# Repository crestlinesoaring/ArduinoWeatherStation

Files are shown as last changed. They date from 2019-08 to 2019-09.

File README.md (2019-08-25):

# ArduinoWeatherStation
### Open source weather station code and hardware for foot launched flight (FLF)

## Assumptions: 
- You have a bash style shell 
-- Linux: terminal
-- Windows: [GitBash for Windows | https://gitforwindows.org/ ]
- There is a root folder that you use for for development
-- referred to as $DEV_HOME
-- I use ~/Development (or C:\Development)

## Software Requirements

- Development tools Setup
-- [Arduino IDE | https://www.arduino.cc/en/Main/Software]

## Hardware Requirements
-- Arduino Mega
-- Brain board (TODO: needs circuit diagram and parts list etc) 

## Get and Build Software

-- Clone this repo (and submodules)

`
git clone --recursive https://github.com/crestlinesoaring/ArduinoWeatherStation.git
`

## Installation

## Testing (Bench) 

## Forks/Contributions
The goal is to build a robust and readily reproduced weather station for FLF oriented micro-meterology. Forks, contributions, issue reports and constructive feedback are welcome. 
Please contact: [Project Coordinator] for more informtaion on contributing source code.

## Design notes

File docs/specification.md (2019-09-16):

++ Weather Station Specifications

* When the local time is 2 hours before sunrise
*  And battery capacity is at or above 25%
* Then System shall store weather data to external eeprom every 5 minutes

* When the local time is after sunrise
*  And Solar panel production exceeds 50% of capacity
*  Or battery capacity is at or above 25%
* Then System shall send stored esternal eeprom weather data
*  And System shall store weather data to memory every 1 minutes
*  And System shall send stored weather data every 5 minutes

* When  solar production drops below 50% of capacity
*   Or the local time is 30 minutes before sunset
* Then System shall stop storing and sending weather data

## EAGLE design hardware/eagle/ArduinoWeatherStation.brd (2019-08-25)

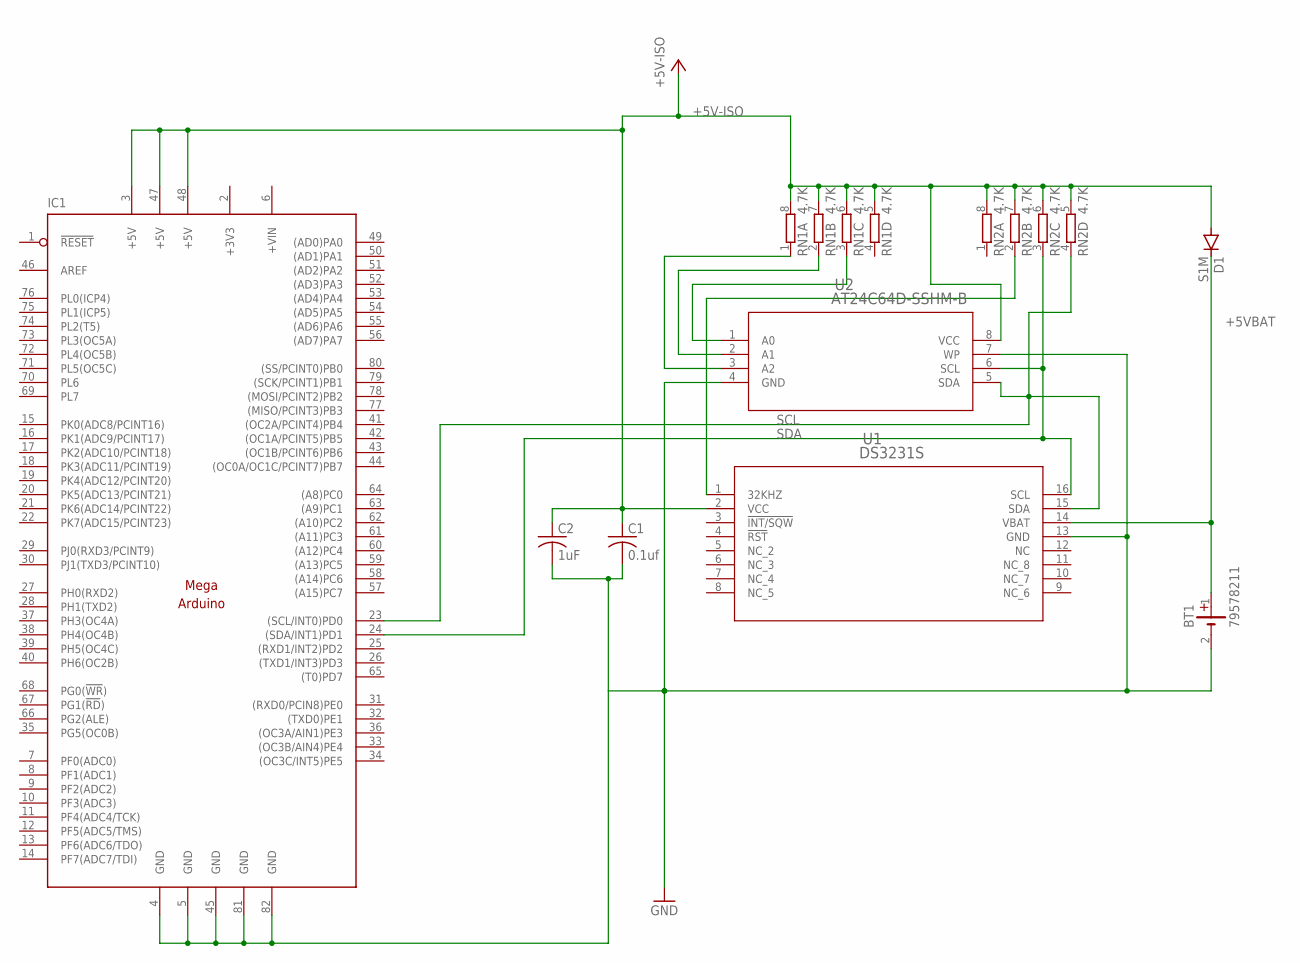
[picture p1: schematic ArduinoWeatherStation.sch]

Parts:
BT1: 79578211
C1: 0.1uf; C0603
C2: 1uF; C0603
D1: S1M; SMA
IC1: MEGAARDUINO_1; MEGA_ARDUINO
RN1, RN2: 4.7K; 0603-ARC
U1: DS3231S; 21-0042B_16
U2: AT24C64D-SSHM-B; 8S1

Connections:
+3V3: IC1.2 (+3V3)
+5V-ISO: C1.1, C2.1, D1.A, IC1.3 (+5V), IC1.47 (+5V), IC1.48 (+5V), RN1.5 (2), RN1.6 (2), RN1.7 (2), RN1.8 (2), RN2.5 (2), RN2.6 (2), RN2.7 (2), RN2.8 (2), U1.2 (VCC), U2.8 (VCC)
+5VBAT: BT1.1 (+), D1.C, U1.14 (VBAT)
+VIN: IC1.6 (+VIN)
GND-ISO: BT1.2 (-), C1.2, C2.2, IC1.4 (GND), IC1.5 (GND), IC1.45 (GND), IC1.81 (GND), IC1.82 (GND), U1.13 (GND), U2.4 (GND), U2.7 (WP)
unnamed: RN2.2 (1), U1.1 (32KHZ)
unnamed: RN1.3 (1), U2.1 (A0)
unnamed: RN1.2 (1), U2.2 (A1)
unnamed: RN1.1, U2.3 (A2)
SCL: IC1.23 ((SCL/INT0)PD0), RN2.4 (1), U1.15 (SDA), U2.5 (SDA)
SDA: IC1.24 ((SDA/INT1)PD1), RN2.3 (1), U1.16 (SCL), U2.6 (SCL)

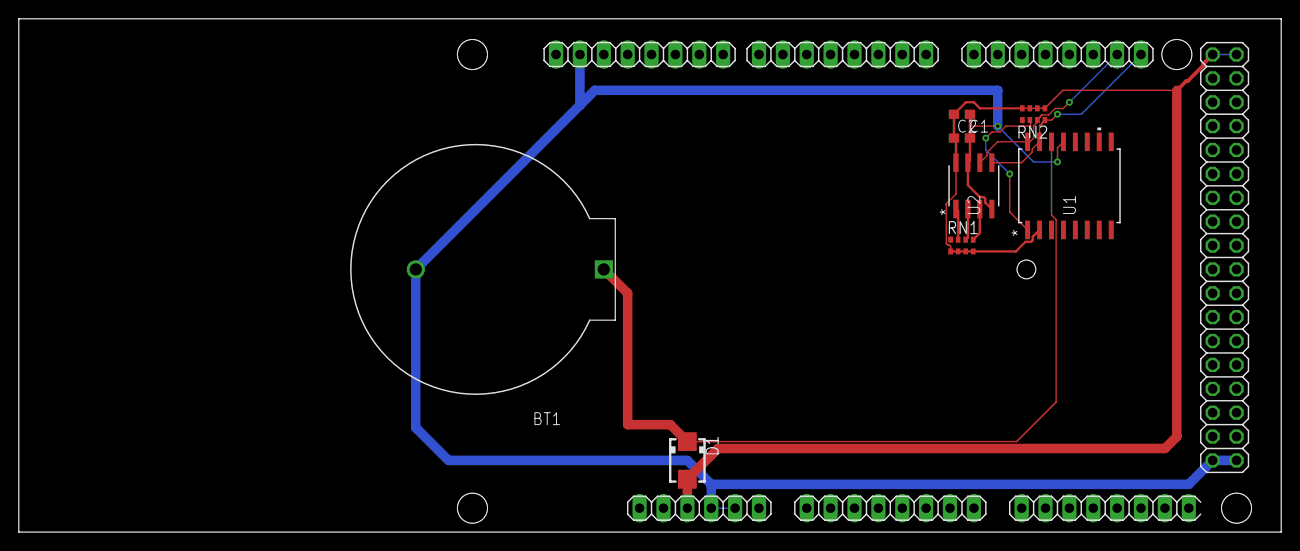
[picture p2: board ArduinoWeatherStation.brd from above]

Board: 2 copper layers, 134.3 x 54.6 mm, 9 parts (0 on the bottom side), 9 nets.

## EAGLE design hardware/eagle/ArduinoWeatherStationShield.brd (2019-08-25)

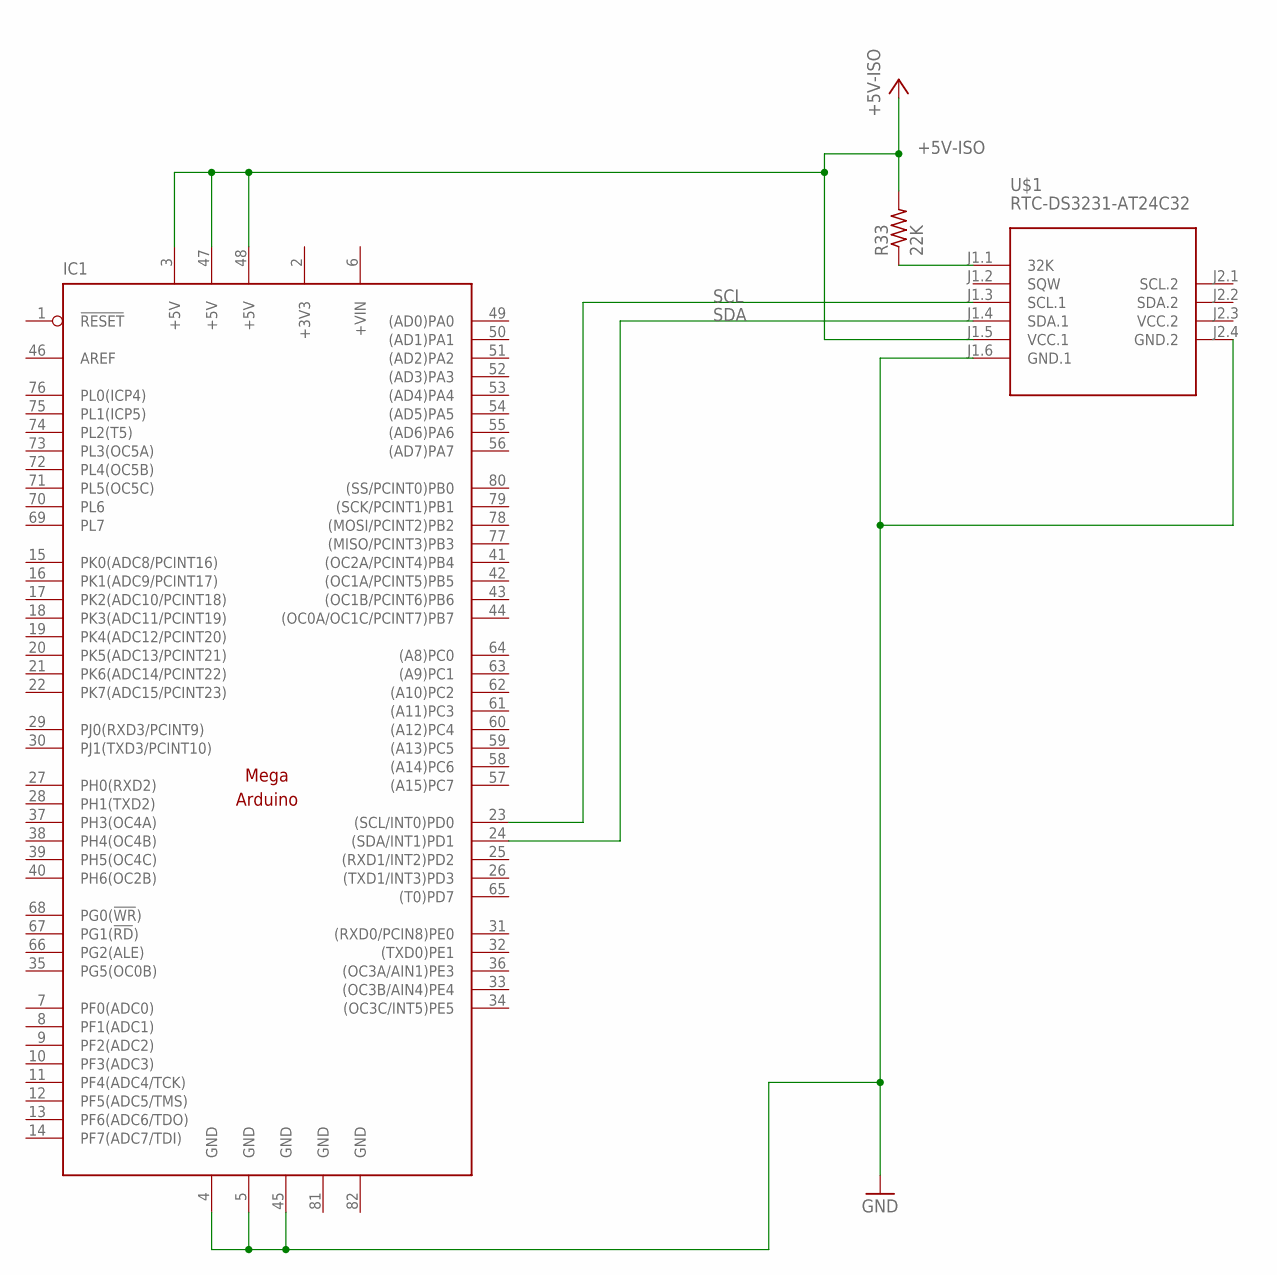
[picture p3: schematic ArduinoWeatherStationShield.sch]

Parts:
IC1: ARDUINO-MEGA-HEADER; MEGA_ARDUINO
R33: 22K; R0402
U$1: RTC-DS3231-AT24C32

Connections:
+3V3: IC1.2 (+3V3)
+5V-ISO: IC1.3 (+5V), IC1.47 (+5V), IC1.48 (+5V), R33.2, U$1.J1.5 (VCC.1)
+VIN: IC1.6 (+VIN)
GND-ISO: IC1.4 (GND), IC1.5 (GND), IC1.45 (GND), IC1.81 (GND), IC1.82 (GND), U$1.J1.6 (GND.1), U$1.J2.4 (GND.2)
unnamed: R33.1, U$1.J1.1 (32K)
SCL: IC1.23 ((SCL/INT0)PD0), U$1.J1.3 (SCL.1)
SDA: IC1.24 ((SDA/INT1)PD1), U$1.J1.4 (SDA.1)
VCC.2: U$1.J2.3 (VCC.2)

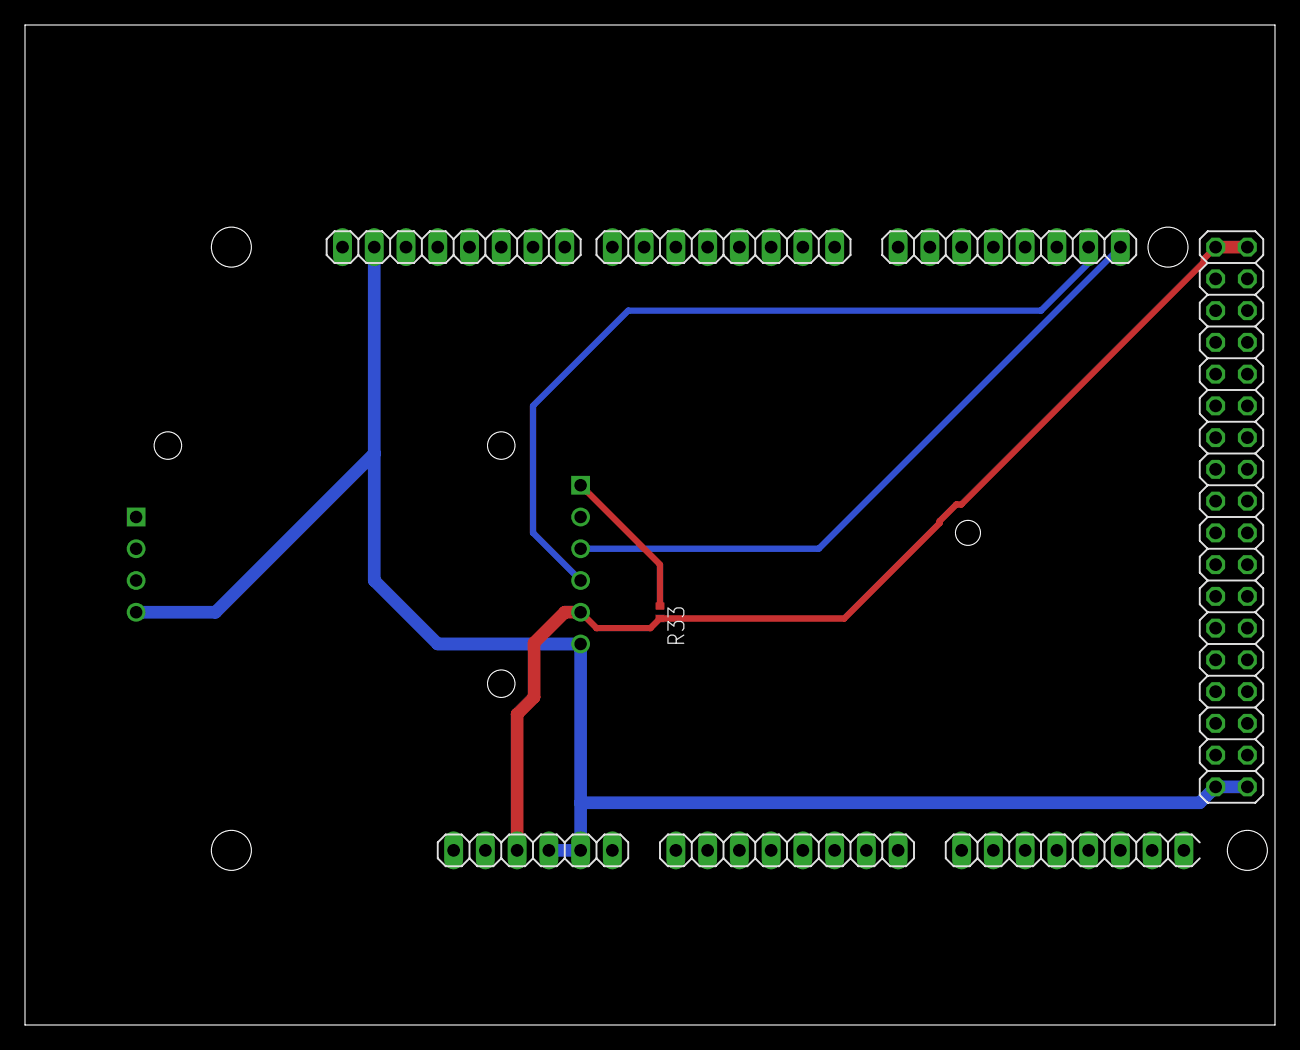
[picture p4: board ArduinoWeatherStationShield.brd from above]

Board: 2 copper layers, 100.0 x 80.0 mm, 3 parts (1 on the bottom side), 5 nets.

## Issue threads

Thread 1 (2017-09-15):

Reported wind directions are sometimes incorrect

BenjaminPelletier, 2017-09-15:
From Jimmy's email:

> we're experiencing some off directions on MArshall, don't know yet what it could be. Lance checked the raw data from the past week and noticed some incorrect alignments, and will look into that next week.

lrocker, 2017-10-10:
Resolved by Jimmy finding the cabling had been inadvertently shorted in the tubing on the way to the windvane. Replaced cabling, ADC values are very solid and repeatable now.

Closed 2017-10-10.

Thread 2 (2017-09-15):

Ping Marshall before sending data

BenjaminPelletier, 2017-09-15:
Right now, we just wait 30 seconds for the Ubquiti to boot up before sending data.  It would be better if we ping before sending data upon power on.

From Jimmy's email:

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

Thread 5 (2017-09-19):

New arrangement of vane circuit

CSSMWX, 2017-09-19:
To maximize A/D resolution this arrangement will be used:
5V -> 4173 (~3900+270) Ohm -> Pin 1 of the vane jack -> vane resistors-> Pin 4 of the vane jack -> GND
and
Pin 1 of the vane jack -> 1K resistor -> Pin 3 of Mega
and
Pin 3 of Mega -> 100nF capacitor -> GND

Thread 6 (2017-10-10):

Save data for batch uploading

lrocker, 2017-10-10:
To facilitate power management, data needs to be saved and then uploaded periodically.
Initially, saving in RAM will be sufficient, and it is understood that the data will not persist and will not be uploaded in case of WatchDog reset, power cycling, or other failure.
Expected upload intervals are once every 5 minutes for daytime "reduced power" modes, and once every hour for night time power saving modes.
Eventually saving to EEPROM or SD will be considered for implementation so data can persist across different failures. That will be addressed in a separate issue.

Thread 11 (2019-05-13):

Save And Send

SaidPar, 2019-05-13:
SaS (Save and Send) is the method/routine to save weather and other data onto memory each minute, and send the accumulated (minutes') data after a variable time to CSS.

Sending in less intervals helps preserve power, as each "send" powers up the WiFi link and the Ethernet card, both of which consume very much power.

The (variable) time of saving vs sending can range from 5 minutes to nearly a whole day.
Now for over a year (2018) we were sending data only each 5 minutes, which seems to be sufficient.

Amount of Data/Memory needs:
Maximum memory needed (uncompressed data):
As of 6. Jan 2019 our raw data is roughly 50 Bytes per minute (please check!).
example 6. Jan 2019

11:25,1/5/2019,14.7,20,180,,,,,M,21s,,10.06,29,0455,14.5,0203,14.14,07:27,X,,2038

On bad days, or when power is low, we need to reduce sending intervals and record up to the whole day.
We are not interested in any data from after sunset until midnight, so we won't need to save those hours.

(please help specify actual sunset times during year, will use 8pm for calculations)
24 x 60 =1440 minutes (A day)
-4 x 60 = 240 (latest Sunset is 8pmish 1. July)
= 1200 minutes

Because resets and reboots may happen while data is being recorded, M's RAM (which is overwritten by reboots) cannot be used and a non-volatile memory sized at least 60KByte (1200 x 50 Bytes=60000 Bytes) is needed.

Memory:
M's available storage is not enough to save as much.
After consideration of FRAM, Flash, NV Sram and EEPROM, an EEPROM was chosen to save the data.

The voltage (5V) and case (SO-8) used on the RTC module allows us to use EEPROMs up to 2Mbits.

A 2MBit (262144 Bytes) EEPROM is installed onto the ZS-042 DS3231 RTC module.
These EEPROMS are Byte-wise and arranged as 1024 "lines" with each line containing 256 Bytes of memory.

The arrangement can be considered as an array of 1024 "lines" with 256 bytes each line.
Whenever any Byte in a line is changed, that whole line, i.e. all 256 bytes are erased and rewritten.

Addressing:
To simplify the addressing, and to reduce wear&tear of the EEPROM, the EEPROM is addressed by its "lines".
Given the 50 bytes of data for every minute, each 256 Bytes line can hold up to 5 minutes of uncompressed raw data. At the end of each 50 bytes an additional Byte is used as a flag.
This gives 5 minutes x (50 Bytes + 1 Byte) = 255 Bytes.

The addressing scheme to use the EEPROM is simple and straightforward:
Every minute the program runs, we strictly use RTC's minute count at that time to form a pointer to that minute's EEPROM line and (one of five) location in that line.
The time from 00:00 to 19:59 equals minute 0 to 1199.
One line of the EEPROM can hold 5 minutes of data (see above, 5 minutes x (50 Bytes + 1 Byte) = 255 Bytes)
So 5 minutes of 50 bytes (of data) are stored in each (total 256 Byte) "line".
1200 minutes divided by 5 minutes = 240 "lines".

Once the address is formed, the data of that minutes is stored.
At the end of each five "50 bytes for each minute data" sections a flag is set.
For now that flag only denotes if the data has been transmitted to CSS or not.

(Note: Arduino wire library limits transfers to 30 Bytes or so. Use EEPROM library from Christensen??)

The SaS function's parameter:
Depending on time (nights) or power (low power condition) or bad weather (strong north winds), the variable handed to this routine can be the default 5 minutes, or spanning from midnight until sunrise (nights), or hourly (bad weather), or 12 hours (really low power).
The nonvolatile SaS variable can be updated/changed by the program depending on conditions like power etc.

Sending:
When the RTC's time carries :x0 minutes or :x5 minutes in it's last digit, the current RTC time plus the SaS variable are used to determine if the accumulated minutes have to be sent or not. A nonvolatile SaS "line" counter is set to RTCtime minus SAS and the first line is read and checked for the 5 consecutive 51st flags (Bytes). If that byte is "FF" it means it has been sent (or no data was recorded for that minute) and the next 51st flag is checked. Once a "0" flag is encountered, the data of that minute is sent and the flag is set to "FF". This continues until the current minute, when all data has been sent. Then SaS is set to the current time. If sending is interrupted by a reboot or reset, in the next cycle the same process checks each 51st Byte and picks sending up where the prior send session stopped. TBC

Once a line has been sent (successfully??), the flags at the end of each minute (51th Byte) which was sent is erased.

Ping before sending?

SaidPar, 2019-05-13:
@lrocker @CSSMWX

on sunny days do we also want to record weather data to the EEPROM, or is this reserved for low power days only?

CSSMWX, 2019-05-13:
From my end, to keep things (SaS) simple, I think weather data should be always recorded to EEPROM.
It helps in case the data was not sent (internet is down, happens even on sunny days).
Or a reset/reboot happened.
It simplifies also the pointer to the data array, every saved minute(s) of the day has it's fixed position.

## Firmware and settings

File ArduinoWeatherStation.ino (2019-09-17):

/**********************************************************************************

   ArduinoWeatherStation.ino

   An open source weather station collection applicaiton to be run on an Arduino Mega

*/
const String wxVersion = "21w";
const bool   disableNTP = true;             // Set to false to allow NTP, but it can cause crashes if it doesn't get a response.
const bool   enableEthDump2Serial = false;  // Set to false to suppress spitting Ethernet output to serial. Sometimes unprintable characters mess up the terminal.
const String startupMessage = "UM Weather Station (ver 21w 2019/04/10)";
const byte   wifiStartupDelay = 55;         // Seconds to wait for Ubiquity Wifi startup
int minutesBeforeSunrise = 30;              // Minutes before sunrise to wake and start sending data.
int minutesAfterSunset = 30;                // Minutes after sunset to stay awake before sleep().
//#define TENMINUTEDAY                      // DEBUG: Either switches between night and day every 10 minutes, or doesn't go to night mode.


#include <avr/wdt.h>   // WatchDog Timer. If I hit an endless loop, reset.
#include <avr/sleep.h> // to put Arduino to sleep
#include <avr/power.h> // to put ADC etc to sleep
#include <EEPROM.h>    // write to built-in Arduino EEPROM
#include <Wire.h>         //http://arduino.cc/en/Reference/Wire
#include <math.h>      // Need cos() for calculating sunrise & sunset
#include <Time.h>      // https://github.com/PaulStoffregen/Time  but this header doesn't seem to be needed?
#include <TimeLib.h>   // https://github.com/PaulStoffregen/Time
#include <DS3232RTC.h> // https://github.com/JChristensen/DS3232RTC, using a DS3231, but it's still supported.
#include "SdFat.h"     // https://github.com/greiman/SdFat, Read & write SD card for data logging.
#include "Adafruit_INA219_5A.h"  // Voltage/Current sensor. https://github.com/adafruit/Adafruit_INA219 !! modified to read 5 amps, must get custom version (_5A) from us.
#include "SparkFunBME280.h"      // High precision Temp & Humidity sensor. https://github.com/sparkfun/SparkFun_BME280_Arduino_Library
// TODO: change to site.h and include a sample site.h file

#include "site.h"  // Site-specific parameters - configure for your site

// Configuration definition
#include "wxConfig.h"
#include "wxCache.h"
#include "eeprom.h"


#include "pins.h"      // Header file for hardware dependent variables. Some hardware versions have different devices on different pins.


#include <SPI.h>
#include <Ethernet.h>
#include <EthernetUdp.h>
#include <utility/w5100.h>

#include <sunMoon.h>

// Sunrise calculator
sunMoon sunCalc;

//#define logOneLine( line) logFile.println(line); Serial.println(line);
//#define logOneLine2( line, base) logFile.println(line, base); Serial.println(line,base);
//#define logSome( line) logFile.print(line); Serial.print(line);
#define logOneLine( line) Serial.println(line);
#define logOneLine2( line, base) Serial.println(line,base);
#define logSome( line) Serial.print(line);

// Dynamic configuration parameters to be saved in EEPROM

Adafruit_INA219_5A ina219a(ina219a_HWaddr);     // First  ina219 sensor: A == Solar Panel
Adafruit_INA219_5A ina219b(ina219b_HWaddr);     // Second ina219 sensor: B == Battery
BME280 bme280a;                                 // First  bme280 sensor: A == inside the mostly-sealed Brain Box
BME280 bme280b;                                 // Second bme280 sensor: B == outside (someday we'll add this)


//TODO: Move to external EEPROM
//-=-=-=-=-=-=-=-=-=-=-=-=-=-=-=-=-=-=-=-=-=-
// EEPROM cells have a write life of 100,000 writes.
//    Once an hour, 24 hours: would last 10 years.
//    Once every 10 minutes, 14 hours a day: 3 years.
//    Once a minute 12 hours a day: gone in 6 months.
//   Keep writes to less than 25 a day, for each cell.
// EEPROM MAP of used addresses
// 00-64 RESERVED (for Ariadne bootloader)
//    65 PowerSave flag
//    66 Watchdog flag
// 67-70 Watchdog time_t
//    71 Ubiquiti stay-on flag
//    72 Transmit interval (not implemented)
//
//    80-81 uInt Boot-up counter (disabled after 25k, burning through it too fast)
//    82-83 uInt watchdog counter
//    84-85 uInt sleep counter
//    86    Byte camera control (on/off, etc)
//    90    Char minutes before Sunrise to wake, -120 to 120, Going negative means not to wake until after sunrise.
//    91    Char minutes after  Sunset to sleep, -120 to 120. Going negative means go to sleep before sunset.
//

// RTC USED ADDRESSES:
//   0x0B rtcWindSpeed, keep the windspeed so we can resume the MMA after a reboot
//
// EE_START_LOG-(EE_MAX_ADDRESS-16)  Log space

//-=-=-=-=-=-=-=-=-=-=-=-=-=-=-=-=-=-=-=-=-=-

const int eePowerSave = 65; ///jjji go beyond ariadnes 64 bytes
const int eeWatchdog = 66;
const int eeWatchdogTime = 67;    // to 70 - four bytes
const int eeKeepUbiOn = 71;
const int eeTransmitInterval = 72;
const int eeBootCounter = 80;     // to 81 - two bytes, suspended because it was writing to eeprom too often.
const int eeWatchdogCounter = 82; // to 83 - two bytes
const int eeSleepCounter = 84;    // to 85 - two bytes
const int eeCamStatus = 86;
const int eeMinutesBeforeSunrise = 90; // Char, -120 to 120
const int eeMinutesAfterSunset = 91;   // Char, -120 to 120
const int eeVoltsLowestSeen = 92;          // Byte, 0 to 254
const int eeVoltsLowestDay = 93;           // Byte, day of month

unsigned int eeUIntTemp = 0;      // Not a memory location, just an int so we can easily write  ints to eeprom.
byte eeByteTemp = 0;              // Not a memory location, just a byte so we can easily write bytes to eeprom.
char eeCharTemp = 0;              // Not a memory location, just a char so we can easily write char (signed, -128 to 127) to eeprom.

struct eeFlags {
  bool powerSave : 1;
  bool keepUbiOn : 1;
  bool flag3     : 1;
  bool flag4     : 1;
  bool flag5     : 1;
  bool flag6     : 1;
  bool flag7     : 1;
  bool flag8     : 1;
};

struct structCamStatus {
  bool SouthDesireOn : 1;
  bool NorthDesireOn : 1;
  bool BrainDesireOn : 1;
  bool badWeather : 1;
  byte padding    : 4;
};

structCamStatus camStatus;
structCamStatus camSnapshotSaveCamStatus;


/* DS3232 Register Addresses
   RTC_SECONDS   0x00
   RTC_MINUTES   0x01
   RTC_HOURS     0x02
   RTC_DAY       0x03
   RTC_DATE      0x04
   RTC_MONTH     0x05
   RTC_YEAR      0x06
   ALM1_SECONDS  0x07
   ALM1_MINUTES  0x08
   ALM1_HOURS    0x09
   ALM1_DAYDATE  0x0A
   ALM2_MINUTES  0x0B  //Stolen for windspeed
   ALM2_HOURS    0x0C  //Stolen for struct RTCmem
   ALM2_DAYDATE  0x0D  //Stolen for struct RTCmem
   RTC_CONTROL   0x0E
   RTC_STATUS    0x0F
   RTC_AGING     0x10
   RTC_TEMP_MSB  0x11
   RTC_TEMP_LSB  0x12
*/

// Store windspeed in the RTC's NVRAM every minute so we can report sensible windspeed immediately after a reboot.
// This would burn up eeprom eventually, so we use the RTC's very very limited nvram.
// Overwriting the ALARM2 minutes location (0x0B) since we don't use ALARM2.
const byte rtcWindSpeed = 0x0B;

//bit cheat-sheet: 4=16, 5=32, 6=64, 7=128, 10=1024, 12=4096
//(ab)using ALARM2 (0x0B-0x0D), we get 24 bits of NVRAM. NOT USED YET, just a framework.
struct RTCmem {
  byte         windSpeed       :  4;  // multiply by 2, stores up to 32
  unsigned int batt_mAh        : 11;  // multiply by 3, stores up to 6,144 mAh discharge; zero = full charge.
  unsigned int batt_lastminute :  9;  // multiply by 3, last minute battery discharge was updated, so we can catch-up on sleep expenditures by estimating usage.
};

//-=-=-=-=-=-=-=-=-=-=-=-=-=-=-=-=-=-=-=-=-=-=-=-=-=-=-=-=

//Global Variables
//-=-=-=-=-=-=-=-=-=-=-=-=-=-=-=-=-=-=-=-=-=-=-=-=-=-=-=-=
unsigned long lastSecond;   //The millis counter to see when a second rolls by
unsigned long loopCounter;  //see how often we loop
unsigned long loopDelta;    //see how many loops since the last print
unsigned long msTemp;       //store millis() now and then to see how long something took, for Serial.print()s all over
unsigned long usTemp;       //store micros() now and then to see how long something took. Much smaller than millis!
byte seconds;               //When it hits 60, increase the current minute
byte minutes;               //Keeps track of where we are in various arrays of data
byte minutes_10m;           //Keeps track of where we are in wind gust/dir over last 10 minutes array of data
byte minutes_5m;            //Keep track of wind gust over previous 5 minutes.
byte hours;
int days;                   //Yes I'm optimistic
int sunrise;                //Minutes after midnight for sunrise
int sunset;                 //Minutes after midnight for sunset
int minutesToday;           //Updated each minute to current time. In minutes.
byte telnetSeconds = 0;     //Seconds spent in a telnet session.
byte sunriseDay = 0;        //Day we last calculated sunrise/sunset for. If it's not today, calc again.
byte lastRealMinute;        //Keep track of when it's a new minute() (Real time, not runtime). Used to check for second() == 0, but that's not reliable.
bool justBooted = true;     //Some stuff settles after the first minute, so let's keep track of that.
bool justRestarted = true;  //Print an R at the end of the first upload attempt to make it easy to see a reboot.
bool powerSave = false;     //Set a flag when we're in power save mode. Do some stuff different.
bool isDaytime = false;
bool ethEnabled = false;    //Set once Eth is enabled because enabling incurs a 30 second pause that we don't want to repeat.
bool wifiEnabled = false;   //Set once wifi is enabled so we don't transmit when it's not on.
bool keepUbiquitiOn = false;    // Used for testing, when we need the wifi to stay powererd on all day.
bool pauseSolar = false;    //We need to charge pausing when it gets hot or if charging too fast. It == battery, box, outside, etc...
byte pauseSolarMinutes = 2; //How long to leave solar off when we turn it off.
byte resumeSolarMinutes = 3;//How long to leave solar ON even if charge rate is high.
float pauseSolarChargeCurrent;  //Store the battery charging rate that resulted in a solar panel "pause" so we can report it.
time_t wifiStartTime = 0;   // Ubiquiti M5 takes ~64 seconds to start, need to keep track of when it started.
time_t pauseSolarStartTime; //Keep track of when we paused the solar panel so we can leave it off for a set time.
time_t resumeSolarStartTime;//Similarly, what time we resumed so we don't cut it off too fast.
time_t uploadPending = 0;   //Set it to the time when a pending upload starts. Don't shut off wifi if one is pending. At least not for 2 or 3 minutes or something.
time_t camSnapshot = 0;     //Used when we want to take and upload a power-efficient single picture from the cameras.
time_t reportWatchdog = 0;  //Do we need to report a watchdog reset?
time_t recentTime = 0;      //Set the current time periodically so we can use it in the Watchdog Interrupt
time_t lastCrashTime = 0;
time_t lastUploadTime = 0;  // Keep track of the last (hopefully successful?) upload, so we know what still needs to be uploaded.
const char charComma = ',';       //Save memory with Serial.print(charComma) instead of Serial.print(",") all over.
//const char compile_date[] = __DATE__ " " __TIME__;

long lastWindCheck = 0;
int minuteWindClicks = 0;
volatile long lastWindIRQ = 0;
volatile byte windClicks = 0;
volatile byte pin18Clicks = 0;
volatile byte pin19Clicks = 0;

// For Marshall weather, keep track of and report the following:
/*
   1: time
   2: date
   3: Wind speed mph, 1 min avg
   4: Wind speed mph, 10 min Peak (needs to change to 5 min peak)
   5: Wind direction, 1 min avg
   6: Temerature in F, outside, current
   7: Humidity, outside, current
   8: Barometric pressure in kPa (divide by 100), sampled once a minute
   9: Barometric pressure delta since last sample (1 minute ago)
   10: rain for the day (not used, set to -LR- for identification)
   11: rain long term?  (not used, set to -LR- for identification)
   12: Temperature in C from RTC
   13: Humidity, inside enclosure, currently same as #7
   13: current 1: solar panel
   14: voltage 1: solar panel
   15: current 2: battery
   16: voltage 2: battery
   17: light level (accurate, but probably zero inside enclosure)
   18: uptime in HH:MM:SS
   19: Wind direction text (N, NNW, NW, WNW, W, etc)
   20: Status stuff: reboots, socket status, failures, etc...
*/

float windSpeedAvg = 0; //Lets try keeping avg using MATH!

#define WIND_DIR_AVG_SIZE 60
#define WIND_SPEED_AVG_SIZE 30
#define VOLTAGE_AVG_SIZE 10
int winddiravg[WIND_DIR_AVG_SIZE];  //120 (now 60) ints to keep track of 2 (now 1) minute average.
float windgust_10m[10];             //10 floats to keep track of 10 minute max
float windgust_5m[5];               //5 floats to keep track of highest gust each of the last 5 minutes.
int windgustdirection_10m[10];      //10 ints to keep track of 10 minute max
int windgustdirection_5m[5];        //5 ints to keep track of 5 minute max
volatile float rainHour[60];        //60 floating numbers to keep track of 60 minutes of rain

//These are all the weather values that wunderground expects:
int winddir = 0;              // [0-360 instantaneous wind direction]
unsigned int winddirRaw = 0;  // Keep the raw ADC reading for troubleshooting
float windspeedmph = 0;       // [mph instantaneous wind speed]
float windgustmph = 0;        // [mph current wind gust, using software specific time period]
int   windgustdir = 0;        // [0-360 using software specific time period]
int   winddir_avg2m = 0;      // [0-360 2 minute average wind direction]
float windgustmph_10m = 0;    // [mph past 10 minutes wind gust mph ]
float windgustmph_5m = 0;     // [mph past 5 minutes wind gust]
float windmax_1m = 0;
float windmin_1m = 0;
int   windgustdir_10m = 0;    // [0-360 past 10 minutes wind gust direction]
int   windgustdir_5m = 0;     // 0-360 past 5 minutes wind gust direction
String strWindDir = "ERR";    // N, NNE, NE, ENE, E, ESE, SE, SSE, S, SSW, SW, WSW, W, WNW, NW, NNW
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
void loop()
{

  //Check for incoming Ethernet connections to the open socket - telnet port 23537
  if (wifiEnabled) {
    checkEthIncomingData();
  }

  //Do "once a second stuff", mostly weather. Also keep track of which minute it is.
  int elapsedMillis = millis() - lastSecond;
  if ( elapsedMillis >= 1000 ) {
    //digitalWrite(STAT1, HIGH); //Blink stat LED to show how long we're doing the "once a second" work

    // add one second for every 1000 ms that have passed
    lastSecond += 1000 * (int)(elapsedMillis / 1000);
    seconds += (int)(elapsedMillis / 1000);
    wdt_reset(); //I think once a second is enough for our 8 second watchdog.

    //Calc the wind speed and direction every second for 120 second to get 2 minute average
    float currentSpeed;
    currentSpeed = get_wind_speed();


    windspeedmph = currentSpeed; //update global variable for windspeed when using the printWeather() function
    int currentDirection = get_wind_direction();

    //Calculate 1 min moving average wind speed instead of using an array
    if (windSpeedAvg == 0) windSpeedAvg = currentSpeed;
    float windInc = currentSpeed / WIND_SPEED_AVG_SIZE;
    float windDec = windSpeedAvg / WIND_SPEED_AVG_SIZE;
    windSpeedAvg = windSpeedAvg - windDec + windInc;

    //Check to see if this is a gust for the minute
    if (currentSpeed > windgust_10m[minutes_10m])
    {
      windgust_10m[minutes_10m] = currentSpeed;
      windgustdirection_10m[minutes_10m] = currentDirection;
    }
    if (currentSpeed > windgust_5m[minutes_5m])
    {
      windgust_5m[minutes_5m] = currentSpeed;
      windgustdirection_5m[minutes_5m] = currentDirection;
    }

    //Check to see if this is a gust for the day (assuming daily reboots; this never resets on its own).
    if (currentSpeed > windgustmph)
    {
      windgustmph = currentSpeed;
      windgustdir = currentDirection;
    }

    // Wifi takes ~64 to 80 seconds to come alive, check every second to see if Wifi's ready yet.
    // Use millis() instead of now() because early on (before RTC is set up), now() is invalid.
    if (wifiStartTime) {
      if (not (int((millis() - wifiStartTime) / 1000) % 10)) {
        Serial.print("Waiting for wifi to start up, it's been ");
        Serial.print((millis() - wifiStartTime) / 1000.0, 2);
        Serial.println(" seconds.");
      }
      if ((millis() - wifiStartupDelay * 1000.0L) > wifiStartTime) {
        Serial.println(" Done waiting! Wifi Enabled.");
        enableEthernet(); //? added here is it ok? jjj20f
        wifiStartTime = 0;
        wifiEnabled = true;
      }
    }

    // Once-a-minute tasks; seconds are incremented at the top of loop() and may be > 59 until we get here. Hope that's okay!

    if (seconds > 59)
    {
      seconds = seconds % 60; // sometimes the loop takes longer than 1 second.
      if (++minutes > 59)
      {
        minutes = 0;
        if (++hours > 23)
        {
          hours = 0;
          ++days;
        }
      }
      if (++minutes_10m > 9) minutes_10m = 0;
      if (++minutes_5m > 4) minutes_5m = 0;

      // Zero out this minute's rainfall and gust amounts
      rainHour[minutes] = 0;
      windgust_10m[minutes_10m] = 0;
      windgust_5m[minutes_5m] = 0;

      // Set the RTC if it needs it and we have good time from NTP
      if (timeStatus() == timeSet) {
        // Long as we've got a good time source, only need to update every 10 minutes.
        setSyncInterval(600);
        recentTime = now();             //Update this once a minute. It will be used in the Watchdog ISR to give a rough date/time estimate.

        //Compare RTC to NTP, to set the RTC. Used to check every 10 minutes, now let's just check once an hour at :15 after.
        if (minute() == 15) {
          compareRTCwithNTP();
          Serial.println(returnStatus);
        } // END of once an hour on :15, while the correct date & time are known
      } else if (timeStatus() == timeNeedsSync) {
        //If we don't have valid time, check for time every 2 minutes. Otherwise it's normally once an hour.
        setSyncInterval(120);
        logSome(" time sync lost, interval set to 120s. ");

      } else if (timeStatus() == timeNotSet) {
        if (ina219b_volts > 13.8) {
          logSome(F(" time still not set, enabling wifi & ethernet"));
          enableWifi();
          enableEthernet();
        }
      }  // END of timeStatus() == timeSet

      // Check every minute that we know sunrise/sunset for today. If not, calculate it (roughly).

      if (day() > sunriseDay) getRiseSet();


      // From 11:50 to noon, make sure wifi is powered on, in case we need to do something.
      if (hour() == 11 and minute() >= 49) {

        enableWifi();
        enableEthernet();
      }


      /* **************************************************
          C A M E R A S    CAMERAS    C A M E R A S
          C A M E R A S    CAMERAS    C A M E R A S
          C A M E R A S    CAMERAS    C A M E R A S
       * *************************************************/

      // A short while after sunrise, turn ON the cameras, if charging conditions are good enough.
      if ( (minutesToday > sunrise) and (minutesToday < sunset - 120)
           and (((ina219a_ma > 500) and (ina219a_volts > 14))
                or (ina219a_volts > 17.5))
           and not (camStatus.badWeather)
           and (battDrainmA > -500)) {
        // If it's early enough in the day, and charging voltage is high enough, enable cameras.
        if (keepUbiquitiOn == false) {
          keepUbiquitiOn = true;
          EEPROM.update(eeKeepUbiOn, true);
          enableWifi();
        }
        if (humidityInside < 80) {
          // Cam North is a little wonky, crashes in high humidity. *shrug*. (April 2019)
          enableCamNorth();
        }
        enableCamSouth();
      }


      // Keep track of minutes with battery drain; shut off cameras & full-time Ubiquiti if there isn't enough sun.
      if (ina219b_ma < 0) {
        if (battDrainMinutes < 0) {
          battDrainMinutes = 0;
        }
        battDrainMinutes += 1;
        // If the battery's been draining too long (minutes) or too much (milliamp-minutes), cut the cameras.
        if (not camSnapshot and ((battDrainMinutes >= 5) or (battDrainmA < -8000) or ((ina219b_volts < 12.5) and (battDrainMinutes > 1)) ) ) {
          disableCamSouth();
          disableCamNorth();
          disableCamBrain();
          keepUbiquitiOn = false;
          EEPROM.update(eeKeepUbiOn, false);
          disableWifi();
          disableEthernet();
        }
      } else if ((ina219b_ma > 50) or (ina219a_volts > 16)) {
        // track positive charging moments
        if (battDrainMinutes > 0) {
          battDrainMinutes = 0;
        }
        battDrainMinutes -= 1;
      } else {
        // reset some of the countdown timers.
        battDrainMinutes = 0;
      }
      battDrainmA += ina219b_ma;



      // After 6:30pm, shut off the cameras and Ubiquiti-always-on setting. Once an hour in case we want to manually turn on.
      if ( (hour() >= 18)
           and ((minute() == 28) or (minute() == 29)) ) {
        keepUbiquitiOn = false;
        EEPROM.update(eeKeepUbiOn, false);
        disableCamNorth();
        disableCamSouth();
        disableCamBrain();
      }

      // If a snapshot was requested, cam shutoff is delayed. Check back to see if it's time to shut them off yet.
      if (camSnapshot) {
        checkCamSnapshot();
      }


      /* * * * * * * * * * * * * * * * * *
          P O W E R   S A V E
          P O W E R   S A V E
       * * * * * * * * * * * * * * * * * */
      // Turn off / on some peripherals at night & morning
      minutesToday = hour() * 60 + minute();

#ifdef TENMINUTEDAY
      Serial.println(F("   !!DEBUG: Cycling to NIGHT every TEN minutes because of ""#define TENMINUTEDAY"""));
      //if ( (minute() / 10) % 2 ) {
      if ( false ) {  //Everlasting day!! (for testing 5 minute save & send)
        Serial.println(F("Pretending that it's NIGHT time."));
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

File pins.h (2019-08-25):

//Hardware pin definitions, weather station
//-=-=-=-=-=-=-=-=-=-=-=-=-=-=-=-=-=-=-=-=-=-=-=-=-=-=-=-=
// analog I/O pins
//const byte WDIR = A0;
const byte WDIR = A5; //For Lance, still A5

// digital I/O pins
const byte RAIN = 2;
const byte WSPEED = 3;
const byte STAT1 = 7;


/*
brain1C i2c scan 20.Jan 2018
I2C device found at address 0x40  ! ina219a
I2C device found at address 0x41  ! ina219b (b=battery)
I2C device found at address 0x54  ! EEPROM_HWaddr0
I2C device found at address 0x55  ! EEPROM_HWaddr1
I2C device found at address 0x56  ! EEPROM_HWaddr2
I2C device found at address 0x57  ! EEPROM_HWaddr3
I2C device found at address 0x68  ! RTC
I2C device found at address 0x77  ! bme280a (internal)
*/

// I2C devices
// 0x40  64 Sparkfun Humidity/temp sensor?
// 0x44  68 INA219 on 3rd address (1st address is 0x40, conflicts with humidty sensor)
// 0x41  65 INA219 on 2nd address
// 0x60  96 Sparkfun Humidity/temp sensor?
// 0x76 118 BME280 environmental sensor


const byte ina219a_HWaddr = 0x40;  //0x40 for everyone but Lance. 0x44 for Lance.
const byte ina219b_HWaddr = 0x41;  //battery
const byte bme280a_HWaddr = 0x76;  //Default may be 0x77 depending on mfgr
const byte bme280b_HWaddr = 0x77;


const byte EEPROM_HWaddr0 = 0x54;  // 2Mbit EEPROM on RTC board, 1/4 sector
const byte EEPROM_HWaddr1 = 0x55;  // 2Mbit EEPROM on RTC board, 2/4 sector
const byte EEPROM_HWaddr2 = 0x56;  // 2Mbit EEPROM on RTC board, 3/4 sector
const byte EEPROM_HWaddr3 = 0x57;  // 2Mbit EEPROM on RTC board, 4/4 sector

struct isCamEnabled {
  bool CamNorth : 1;
  bool CamSouth : 1;
  bool CamBrain : 1;
};

const byte PIN_ETH_CONTROL = 8;        // Ethernet power control; on=LOW, off=HIGH
const byte ETH_DISABLED = HIGH;
const byte ETH_ENABLED = LOW;

const byte PIN_CamNorth_CONTROL = 9;      // FETQ3, 12V power to Camera4 (PG launch), Disabled(default)=LOW=Camera4 stays off; Enabled=HIGH=Camera4 turns on
const byte CamNorth_ON = HIGH;            // turn Camera4 on
const byte CamNorth_OFF = LOW;            // (default)=turn off Camera4

const byte PIN_CamSouth_CONTROL = 11;      // FETQ2, 12V power to Camera3 (HG launch), Disabled(default)=LOW=Camera3 stays off; Enabled=HIGH=Camera3 turns on
const byte CamSouth_ON = HIGH;             // turn Camera3 on
const byte CamSouth_OFF = LOW;             // (default)=turn off Camera3

const byte PIN_CamBrain_CONTROL = 12;      // FETQ1, 12V power to Camera1&2 (BB), Disabled(default)=LOW=Camera1&2 stay off; Enabled=HIGH=Camera1&2 turn on
const byte CamBrain_ON = HIGH;             // turn Camera1&2 on
const byte CamBrain_OFF = LOW;             // (default)=turn off Camera1&2

const byte PIN_UBIQUITI_CONTROL = 14;   // FETQ4, 12V power to Ubiquiti AP; Enabled(default)=LOW=Ubiquiti AP stays on, Disabled=HIGH=Ubiquiti AP is off 
const byte UBIQUITI_ON = LOW;           // (default)=turn on Ubiquiti AP
const byte UBIQUITI_OFF = HIGH;         // turn off Ubiquiti AP

const byte PIN_12V_CONTROL = 15;        // Rel4, 12V power to all peripherals; Enabled (default)=LOW=power stays connected, Disabled==HIGH=power is disconnected
const byte CONNECT_12V = LOW;           // (default)=power stays connected
const byte DISCONNECT_12V = HIGH;       // power is disconnected

const byte PIN_SOLAR_CONTROL = 16;      // Rel2, Solar panel connection; Enabled (default)=LOW=panel stays connected, Disabled=HIGH=panel is disconnected
const byte SOLAR_CONNECTED = LOW;       // (default)=panel is disconnected
const byte SOLAR_DISCONNECTED = HIGH;   // panel is disconnected

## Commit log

2017-09-15 Changed Ubiquiti and Eth power control pins to constants
2017-09-15 Replaced all tabs and standardized indents to 2 spaces
    [ArduinoWeatherStation.ino]
2017-09-16 Solar Panel shutoff > 350ma, read both BME280s, etc..
    Added Jimmy's improved setup() ethernet disable/enable routine, sets MISO/MOSI to input I think
    Some small formatting changes too.
2017-09-27 INA219a MMA, some cosmetic fixes
    [ArduinoWeatherStation.ino]
2017-09-28 Cosmetic fixes, formatting.
    A few fixes to make:
    pending, added time output for better diagnostics: Double-check 5 minute solar panel timeout, seems not to last 5 minutes?
    --done (hopefully). Fix formatting for negative numbers (000-77)
    --done. Serial output of what time solar is disabled/enabled
    --done. Multiply both INA readings by 2 (350mA -> 700mA)
    --done. reset count of ina readings to zero each minute. Note it gets about 4,200 readings per minute.
    --done. Remove ethernet's client.read() --> serial because it makes copy/paste difficult.
    --done. Serial output on 35s wait for enableEthernet();
    --done. remove wd= from wind direction ADC
    [ArduinoWeatherStation.ino]
2017-09-30 Fix endless loop in enableEthernet()
    The 30 second pause caused endless looping if a minute rollover happened during that pause, because everything happens when each minute rolls over. Fixed by not running enableEthernet() every minute. It didn't need to run every minute anyway.
    [ArduinoWeatherStation.ino]
2017-09-30 Report solar panel cutoff charging rate
2017-10-03 web server for initiating reboot
    First draft of a web server. It's not good at all, but it seems to work.
    [ArduinoWeatherStation.ino]
2017-10-31 19a, Untested! Power save, 2/10 upload when cloudy
    If the battery mA reading is -50 or lower, then go into "night" mode for minute 2-9 of every 10 minutes. Turns on for 2 minutes, because it can take until the next minute for the U to be ready to tra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
2017-11-01 Remove <300mA eth cutoff; wasn't working
    Some mild power saving if voltage gets too low.
    [ArduinoWeatherStation.ino]
2017-12-05 SD card archive. v.19i
    Archives data to SD card. Still does not send any cached data to the website, but getting close to that.
    Some light logging on WatchDog resets. Mild code cleanup and logic improvements.
    [ArduinoWeatherStation.ino, wxCache.ino]
2017-12-08 19o, send once every 5 minutes
    Improved Ubiquiti enable/disable, new pin architecture (for Brain2).
    Saves up data for 5 minutes, and sends in a batch. No error checking really, and sometimes uploads end up out-of-order. It's not refined yet.
    [ArduinoWeatherStation.ino, wxCache.ino, wxTimeNet.ino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]
2018-02-23 20t, minor cleanup, more telnet commands
    Lots of commands and options. Mostly prep for adding cameras, just debug stuff.
2018-06-01 ver 20x7, minor interrupt counting on pins 18 & 19
2018-09-07 21f; cam control, more telnet commands
    Allow cameras to stay on through reboots by saving their state to eeprom, added "sleep / wake" before / after sunset time to eeprom & telnet so it can be adjusted without uploading a new version. As always, other minor changes and cleanup.
    [ArduinoWeatherStation.ino, wxTimeNet.ino, wxUtilities.ino]
2018-09-14 v. 21j, bugfixes, more telnet commands
    [ArduinoWeatherStation.ino, wxTimeNet.ino]
2018-10-07 21r, basic camera functionality
    Turns cameras on when voltage is high enough, turns them off when running negative too long or voltage gets too low.
    Beginnings of "snapshot request" functionality, but it doesn't actually work yet. The auto-off is so aggressive, we can't keep the cameras on long enough to get manual early-morning or late-evening shots. Trying to add the ability to take a quick snap.
    [ArduinoWeatherStation.ino, wxCache.ino, wxTimeNet.ino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]
2019-01-10 .21t, broken snapshot feature and rename cameras
    [ArduinoWeatherStation.ino, pins.h, wxTimeNet.ino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]
2019-01-24 Fix low hanging compiler warnings.
    [ArduinoWeatherStation.ino, wxCache.ino, wxTimeNet.ino]
2019-04-08 .21v, cameras only after 5 mins charging
2019-04-12 .21w, fix mistakes from .21v
    [ArduinoWeatherStation.ino, wxCache.ino, wxTimeNet.ino]
2019-08-25 -Library updates - RTC initialization without Ethernet - JSON Serial Parser
    [ArduinoWeatherStation.brd, ArduinoWeatherStation.sch, ArduinoWeatherStationShield.brd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]

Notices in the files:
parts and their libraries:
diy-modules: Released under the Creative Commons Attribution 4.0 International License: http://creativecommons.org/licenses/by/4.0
